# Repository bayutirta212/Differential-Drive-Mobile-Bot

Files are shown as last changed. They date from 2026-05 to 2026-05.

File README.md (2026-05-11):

# Differential Drive Bot PCB

Custom PCB design for a compact Differential Drive Robot using ESP32 DevKit V1 (30 Pin).

## Features

- Dual motor differential drive system
- Encoder feedback support
- OLED display integration
- Ultrasonic obstacle detection
- GPIO expansion using multiplexer
- Line tracking sensor support
- Compact PCB layout
- ESP32-based control system

---

# Hardware Components

- ESP32 DevKit V1 (30 Pin)
- JGA12 N20 Motor Encoder
- DRV8833 Dual Motor Driver
- HC-SR04 Ultrasonic Sensor
- SSD1306 OLED Display
- CD74HC4067 16-Channel Multiplexer
- TCRT5000 IR Reflective Sensor

---

# System Overview

This robot uses a differential drive mechanism where each wheel is independently controlled using the DRV8833 motor driver.

The ESP32 handles:
- Motor control
- Encoder reading
- OLED communication
- Ultrasonic sensing
- Multiplexer control
- Sensor data processing

The CD74HC4067 multiplexer is used to expand input capability while minimizing GPIO usage.

---

# Pin Configuration

## DRV8833 Motor Driver

| ESP32 Pin | Function |
|---|---|
| GPIO16 | Motor A IN1 |
| GPIO17 | Motor A IN2 |
| GPIO05 | Motor B IN1 |
| GPIO23 | Motor B IN2 |

---

## Motor Encoder

| ESP32 Pin | Function |
|---|---|
| GPIO39 | Left Encoder A |
| GPIO36 | Left Encoder B |
| GPIO35 | Right Encoder A |
| GPIO34 | Right Encoder B |

---

## HC-SR04

| ESP32 Pin | Function |
|---|---|
| GPIO19 | Trigger |
| GPIO18 | Echo |

---

## SSD1306 OLED (I2C)

| ESP32 Pin | Function |
|---|---|
| GPIO21 | SDA |
| GPIO22 | SCL |

---

## CD74HC4067 Multiplexer

| ESP32 Pin | Function |
|---|---|
| GPIO27 | S0 |
| GPIO26 | S1 |
| GPIO25 | S2 |
| GPIO33 | S3 |
| GPIO32 | SIG |
| GIPO13 | EN |

---

# Repository Contents

- Schematic files
- PCB layout files
- Gerber files
- 3D PCB preview
- Wiring references

---

# Software Compatibility

This project can be programmed using:
- Arduino IDE
- PlatformIO

Recommended Libraries:
- Adafruit SSD1306
- Adafruit GFX
- ESP32Encoder
- NewPing

---

# Applications

- Line follower robot
- Obstacle avoidance robot
- Autonomous mobile robot
- Educational robotics platform

---

# Future Improvements

- IMU integration
- Battery monitoring
- PID motor control
- WiFi telemetry
- ROS compatibility

---

# License

This project is open-source under the MIT License.

---

# Author

Rafael Subally  
Student at Mechatronics Engineering Education  
Universitas Negeri Yogyakarta

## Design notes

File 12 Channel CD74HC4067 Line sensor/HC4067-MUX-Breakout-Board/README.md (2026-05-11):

# HC4067-MUX-Breakout-Board
74HC4067 16-ch analog/digital MUX Breakout Board

This is the Eagle CAD representation of the 74HC4067 breakout board, which can be bought from Sparkfun, ICStation or even eBay and Aliexpress.

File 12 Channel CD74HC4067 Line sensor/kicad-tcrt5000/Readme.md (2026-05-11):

# Kicad Footprint and Symbol for tcrt5000 

## Credits

[3D Model](https://grabcad.com/library/tcrt5000-1) by [Aleksandr Motsjonov](https://grabcad.com/aleksandr.motsjonov-1)

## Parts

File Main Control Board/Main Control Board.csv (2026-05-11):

Reference | Qty | Value | DNP | Exclude from BOM | Exclude from Board | Footprint | Datasheet
Brd1 | 1 | SSD1306 |  |  |  | SSD1306:128x64OLED
C1 | 1 | 0.33uF |  |  |  | Capacitor_SMD:C_0805_2012Metric_Pad1.18x1.45mm_HandSolder
C2 | 1 | 0.1uF |  |  |  | Capacitor_SMD:C_0805_2012Metric_Pad1.18x1.45mm_HandSolder
J1 | 1 | Screw_Terminal_01x02 |  |  |  | TerminalBlock:TerminalBlock_MaiXu_MX126-5.0-02P_1x02_P5.00mm
J2 | 1 | Motor A |  |  |  | Connector_JST:JST_XH_B6B-XH-A_1x06_P2.50mm_Vertical
J3 | 1 | Motor B |  |  |  | Connector_JST:JST_XH_B6B-XH-A_1x06_P2.50mm_Vertical
J4 | 1 | Sensor LFR |  |  |  | Connector_PinHeader_2.54mm:PinHeader_1x08_P2.54mm_Vertical
R1,R2,R3,R4,R5,R6 | 6 | 1k |  |  |  | Resistor_SMD:R_1206_3216Metric_Pad1.30x1.75mm_HandSolder
R7,R8,R9,R10 | 4 | 10k |  |  |  | Resistor_SMD:R_1206_3216Metric_Pad1.30x1.75mm_HandSolder
SW1 | 1 | kanan |  |  |  | Button_Switch_THT:SW_PUSH_6mm
SW2 | 1 | kiri |  |  |  | Button_Switch_THT:SW_PUSH_6mm
SW3 | 1 | atas |  |  |  | Button_Switch_THT:SW_PUSH_6mm
SW4 | 1 | bawah |  |  |  | Button_Switch_THT:SW_PUSH_6mm
SW5 | 1 | select |  |  |  | Button_Switch_THT:SW_PUSH_6mm
SW6 | 1 | back |  |  |  | Button_Switch_THT:SW_PUSH_6mm
U1 | 1 |  |  |  |  | ESP32_Footprints:ESP32_30pin
U2 | 1 |  |  |  |  | DRV8833:DRV8833 Module
U3 | 1 | L7806 |  |  |  | Package_TO_SOT_THT:TO-220-3_Horizontal_TabUp | http://www.st.com/content/ccc/resource/technical/document/datasheet/41/4f/b3/b0/12/d4/47/88/CD00000444.pdf/files/CD00000444.pdf/jcr:content/translations/en.CD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
U4 | 1 | HC-SR04 |  |  |  | Connector_PinHeader_2.54mm:PinHeader_1x04_P2.54mm_Vertical

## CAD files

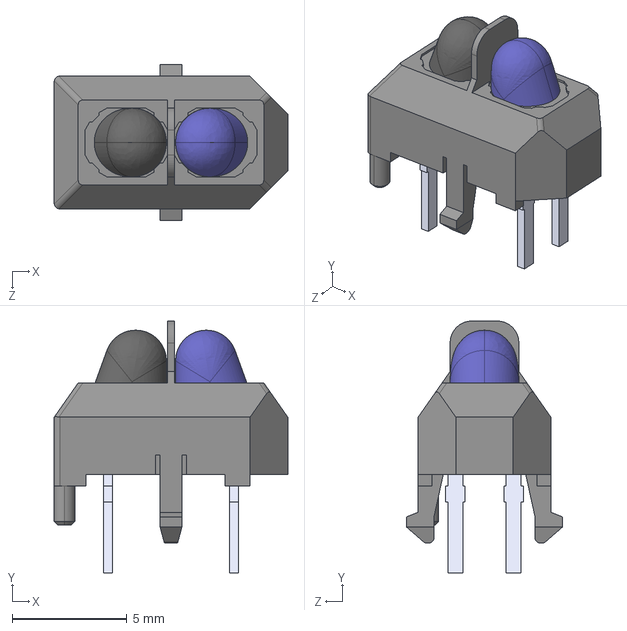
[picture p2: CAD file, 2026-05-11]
12 Channel CD74HC4067 Line sensor/kicad-tcrt5000/tcrt5000.step
10.2 x 11.0 x 6.80 mm

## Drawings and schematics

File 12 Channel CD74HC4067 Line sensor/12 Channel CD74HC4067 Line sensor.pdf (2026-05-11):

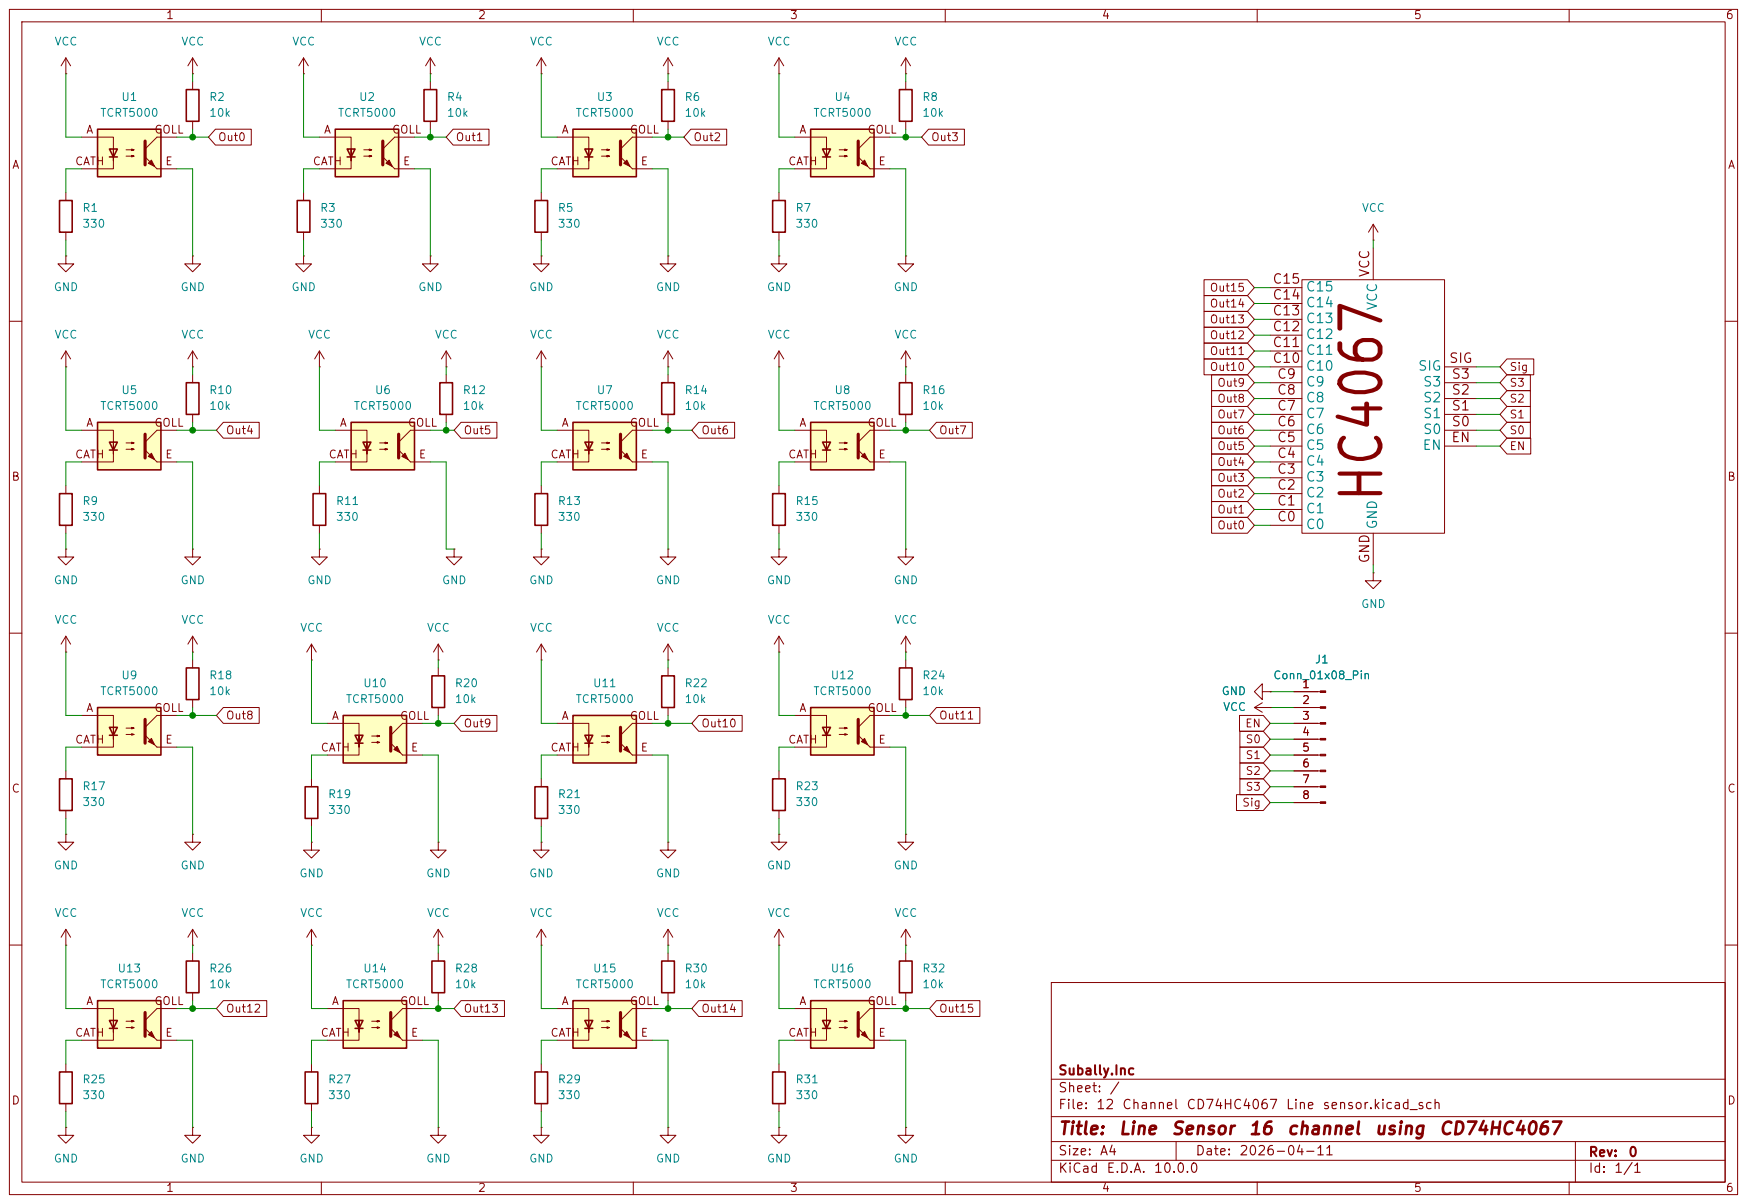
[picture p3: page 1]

Subally.Inc
Sheet: /
D Date: 2026-04-11 KiCad E.D.A. 10.0.0
File: 12 Channel CD74HC4067 Line sensor.kicad_sch
Title: Line Sensor 16 channel using CD74HC4067

Size: A4 | Rev: 0

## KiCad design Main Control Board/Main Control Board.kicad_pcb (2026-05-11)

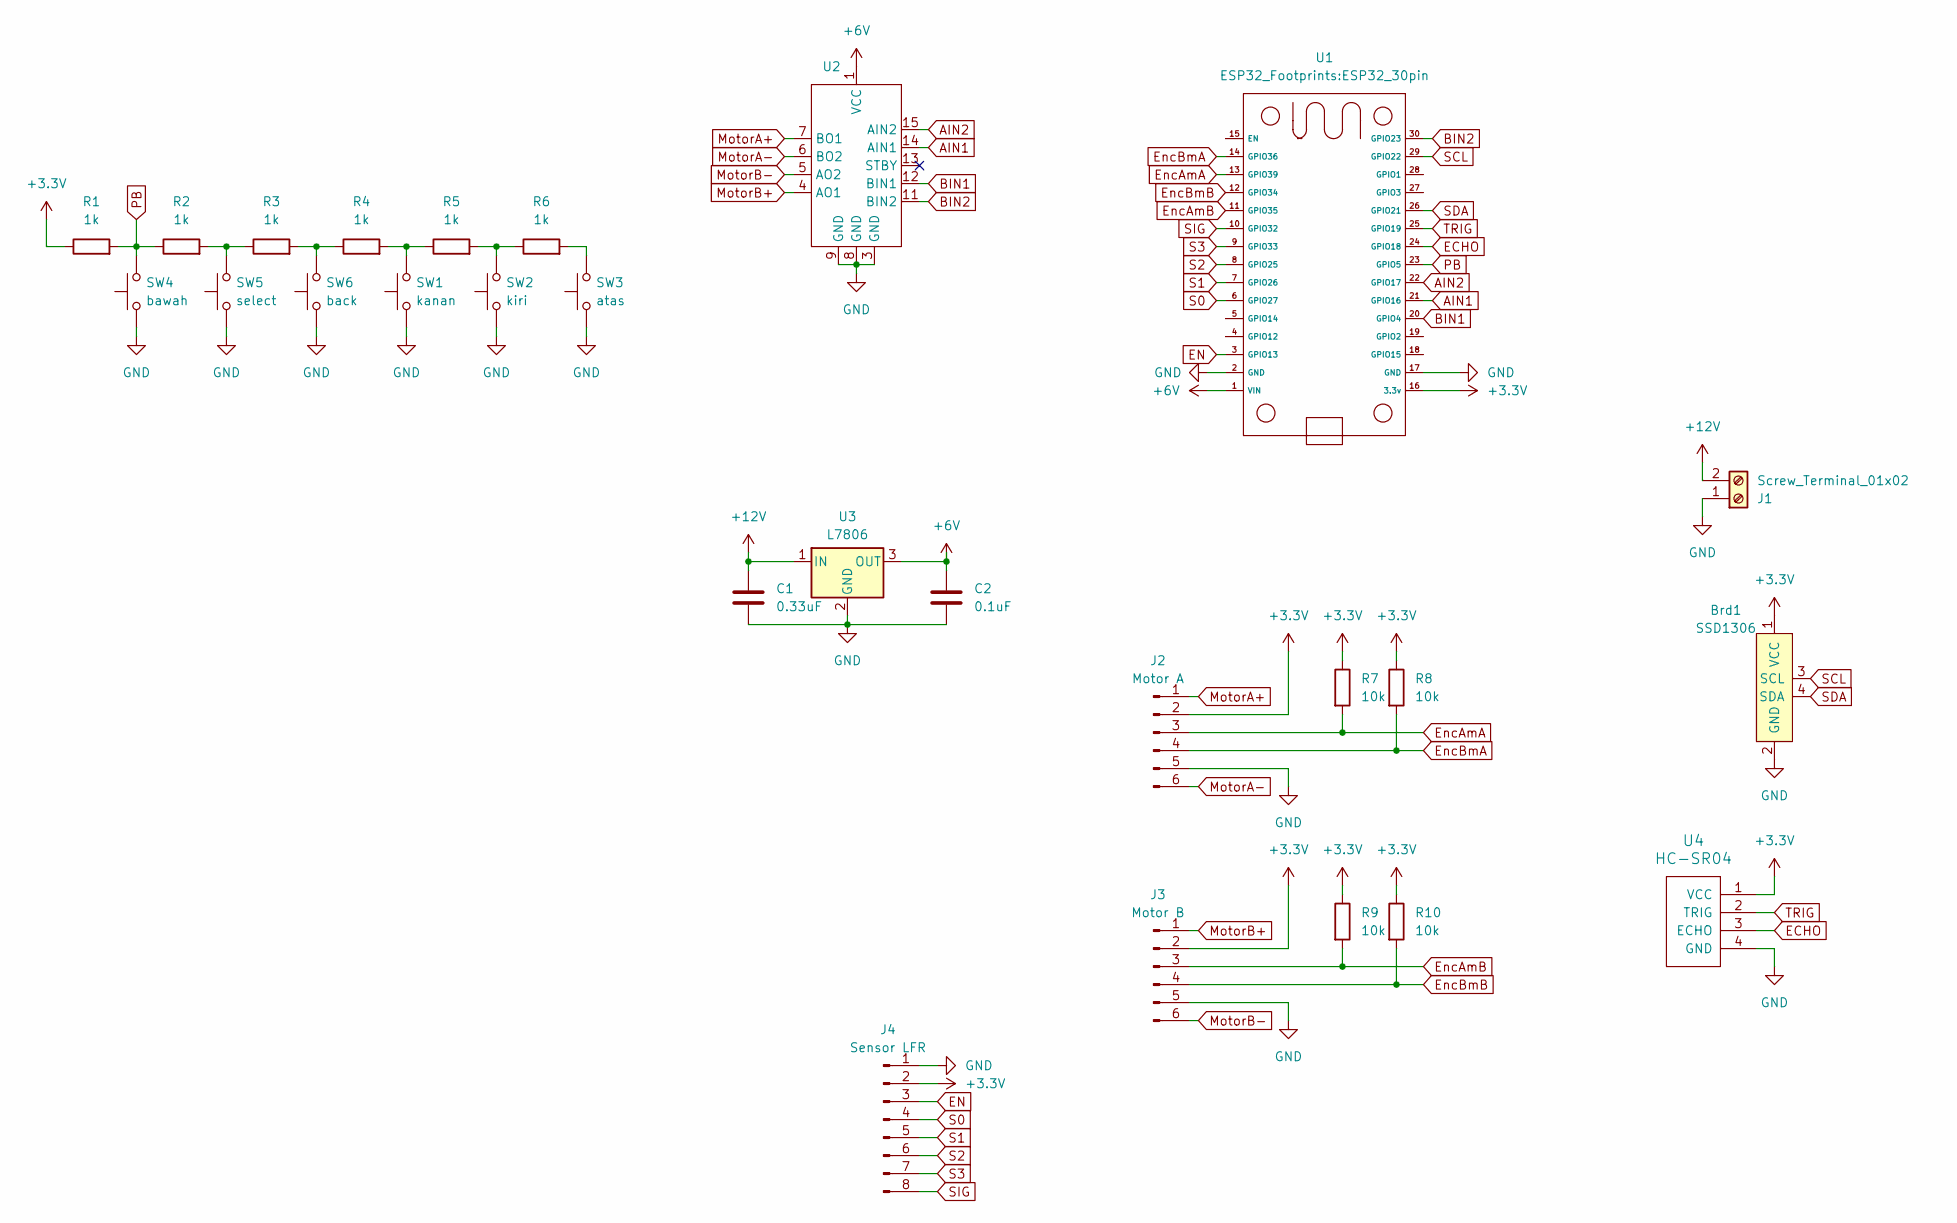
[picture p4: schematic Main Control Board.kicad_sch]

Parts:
Brd1: SSD1306; 128x64OLED
C1: 0.33uF; C_0805_2012Metric_Pad1.18x1.45mm_HandSolder
C2: 0.1uF; C_0805_2012Metric_Pad1.18x1.45mm_HandSolder
J1: Screw_Terminal_01x02; TerminalBlock_MaiXu_MX126-5.0-02P_1x02_P5.00mm
J2: Motor A; JST_XH_B6B-XH-A_1x06_P2.50mm_Vertical
J3: Motor B; JST_XH_B6B-XH-A_1x06_P2.50mm_Vertical
J4: Sensor LFR; PinHeader_1x08_P2.54mm_Vertical
R1, R2, R3, R4, R5, R6: 1k; R_1206_3216Metric_Pad1.30x1.75mm_HandSolder
R7, R8, R9, R10: 10k; R_1206_3216Metric_Pad1.30x1.75mm_HandSolder
SW1: kanan; SW_PUSH_6mm
SW2: kiri; SW_PUSH_6mm
SW3: atas; SW_PUSH_6mm
SW4: bawah; SW_PUSH_6mm
SW5: select; SW_PUSH_6mm
SW6: back; SW_PUSH_6mm
U1: ESP32_30pin
U2: DRV8833 Module
U3: L7806; TO-220-3_Horizontal_TabUp
U4: HC-SR04; PinHeader_1x04_P2.54mm_Vertical

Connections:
+3.3V: Brd1.1 (VCC), J2.2, J3.2, J4.2, R1.1, R7.1, R8.1, R9.1, R10.1, U1.16 (3.3v), U4.1 (VCC)
+6V: C2.1, U1.1 (VIN), U2.1 (VCC), U3.3 (OUT)
+12V: C1.1, J1.2, U3.1 (IN)
AIN1: U1.21 (GPIO16), U2.14 (AIN1)
AIN2: U1.22 (GPIO17), U2.15 (AIN2)
BIN1: U1.20 (GPIO4), U2.12 (BIN1)
BIN2: U1.30 (GPIO23), U2.11 (BIN2)
ECHO: U1.24 (GPIO18), U4.3 (ECHO)
EN: J4.3, U1.3 (GPIO13)
EncAmA: J2.3, R7.2, U1.13 (GPIO39)
EncAmB: J3.3, R9.2, U1.11 (GPIO35)
EncBmA: J2.4, R8.2, U1.14 (GPIO36)
EncBmB: J3.4, R10.2, U1.12 (GPIO34)
GND: Brd1.2 (GND), C1.2, C2.2, J1.1, J2.5, J3.5, J4.1, SW1.1, SW2.1, SW3.1, SW4.1, SW5.1, SW6.1, U1.2 (GND), U1.17 (GND), U2.3 (GND), U2.8 (GND), U2.9 (GND), U3.2 (GND), U4.4 (GND)
MotorA+: J2.1, U2.7 (BO1)
MotorA-: J2.6, U2.6 (BO2)
MotorB+: J3.1, U2.4 (AO1)
MotorB-: J3.6, U2.5 (AO2)
unnamed: R2.2, R3.1, SW5.2
unnamed: R3.2, R4.1, SW6.2
unnamed: R4.2, R5.1, SW1.2
unnamed: R5.2, R6.1, SW2.2
unnamed: R6.2, SW3.2
PB: R1.2, R2.1, SW4.2, U1.23 (GPIO5)
S0: J4.4, U1.6 (GPIO27)
S1: J4.5, U1.7 (GPIO26)
S2: J4.6, U1.8 (GPIO25)
S3: J4.7, U1.9 (GPIO33)
SCL: Brd1.3 (SCL), U1.29 (GPIO22)
SDA: Brd1.4 (SDA), U1.26 (GPIO21)
SIG: J4.8, U1.10 (GPIO32)
TRIG: U1.25 (GPIO19), U4.2 (TRIG)

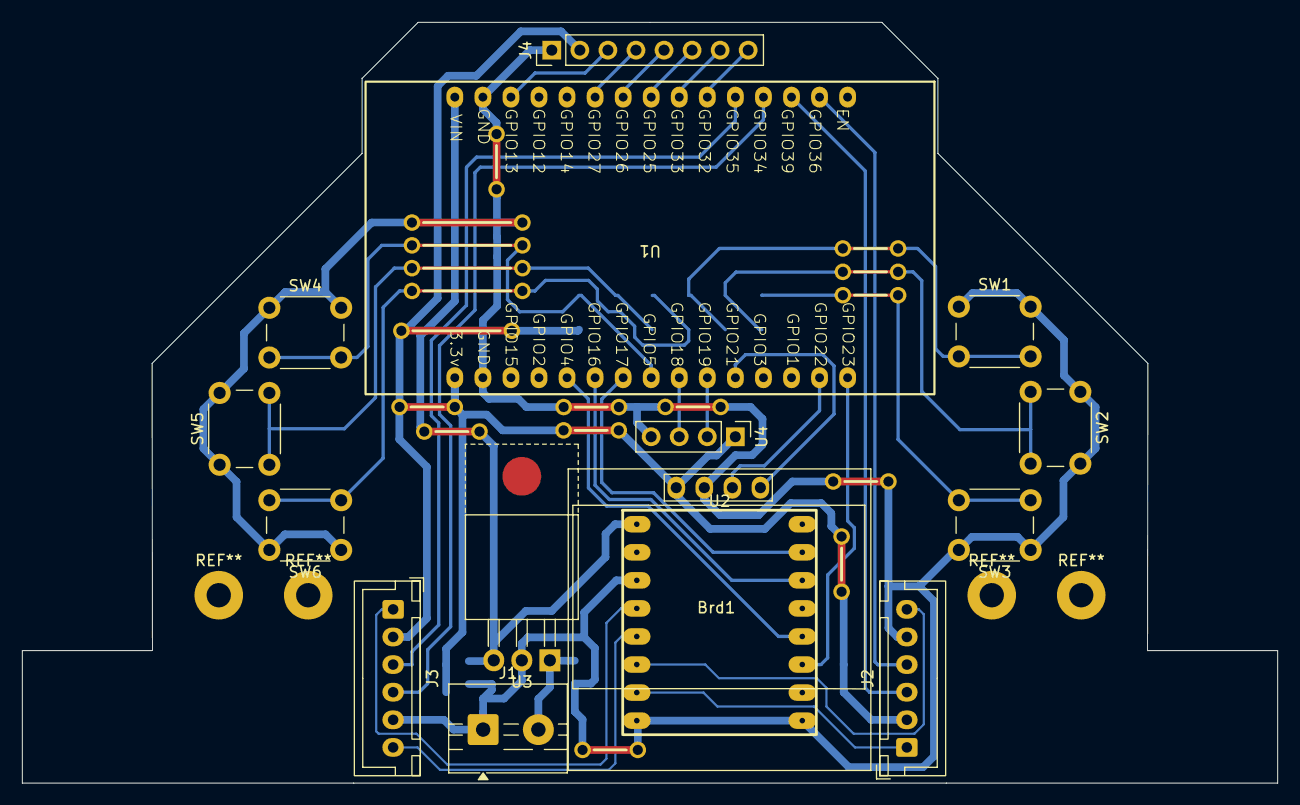
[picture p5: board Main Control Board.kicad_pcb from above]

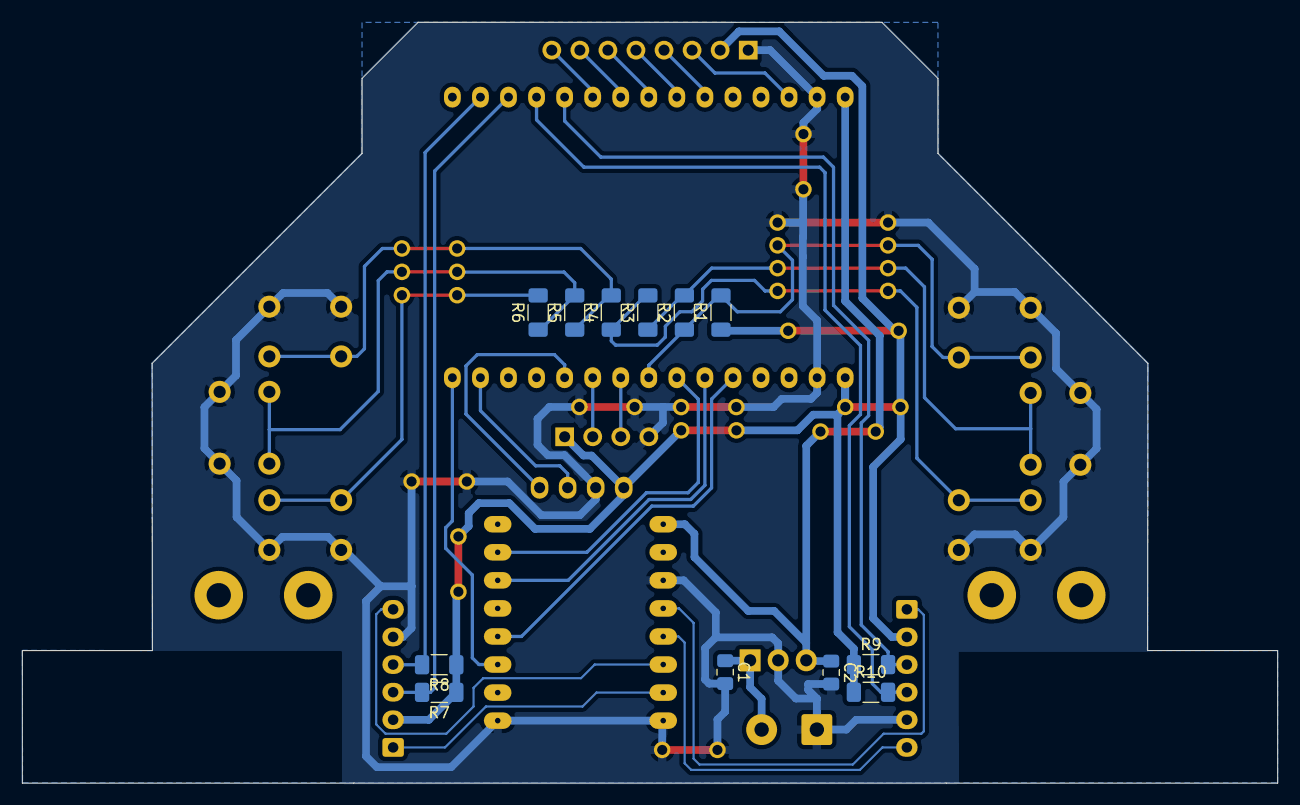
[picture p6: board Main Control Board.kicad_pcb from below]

Board: 4 copper layers, 113.6 x 68.9 mm, 27 parts (12 on the bottom side), 32 nets.

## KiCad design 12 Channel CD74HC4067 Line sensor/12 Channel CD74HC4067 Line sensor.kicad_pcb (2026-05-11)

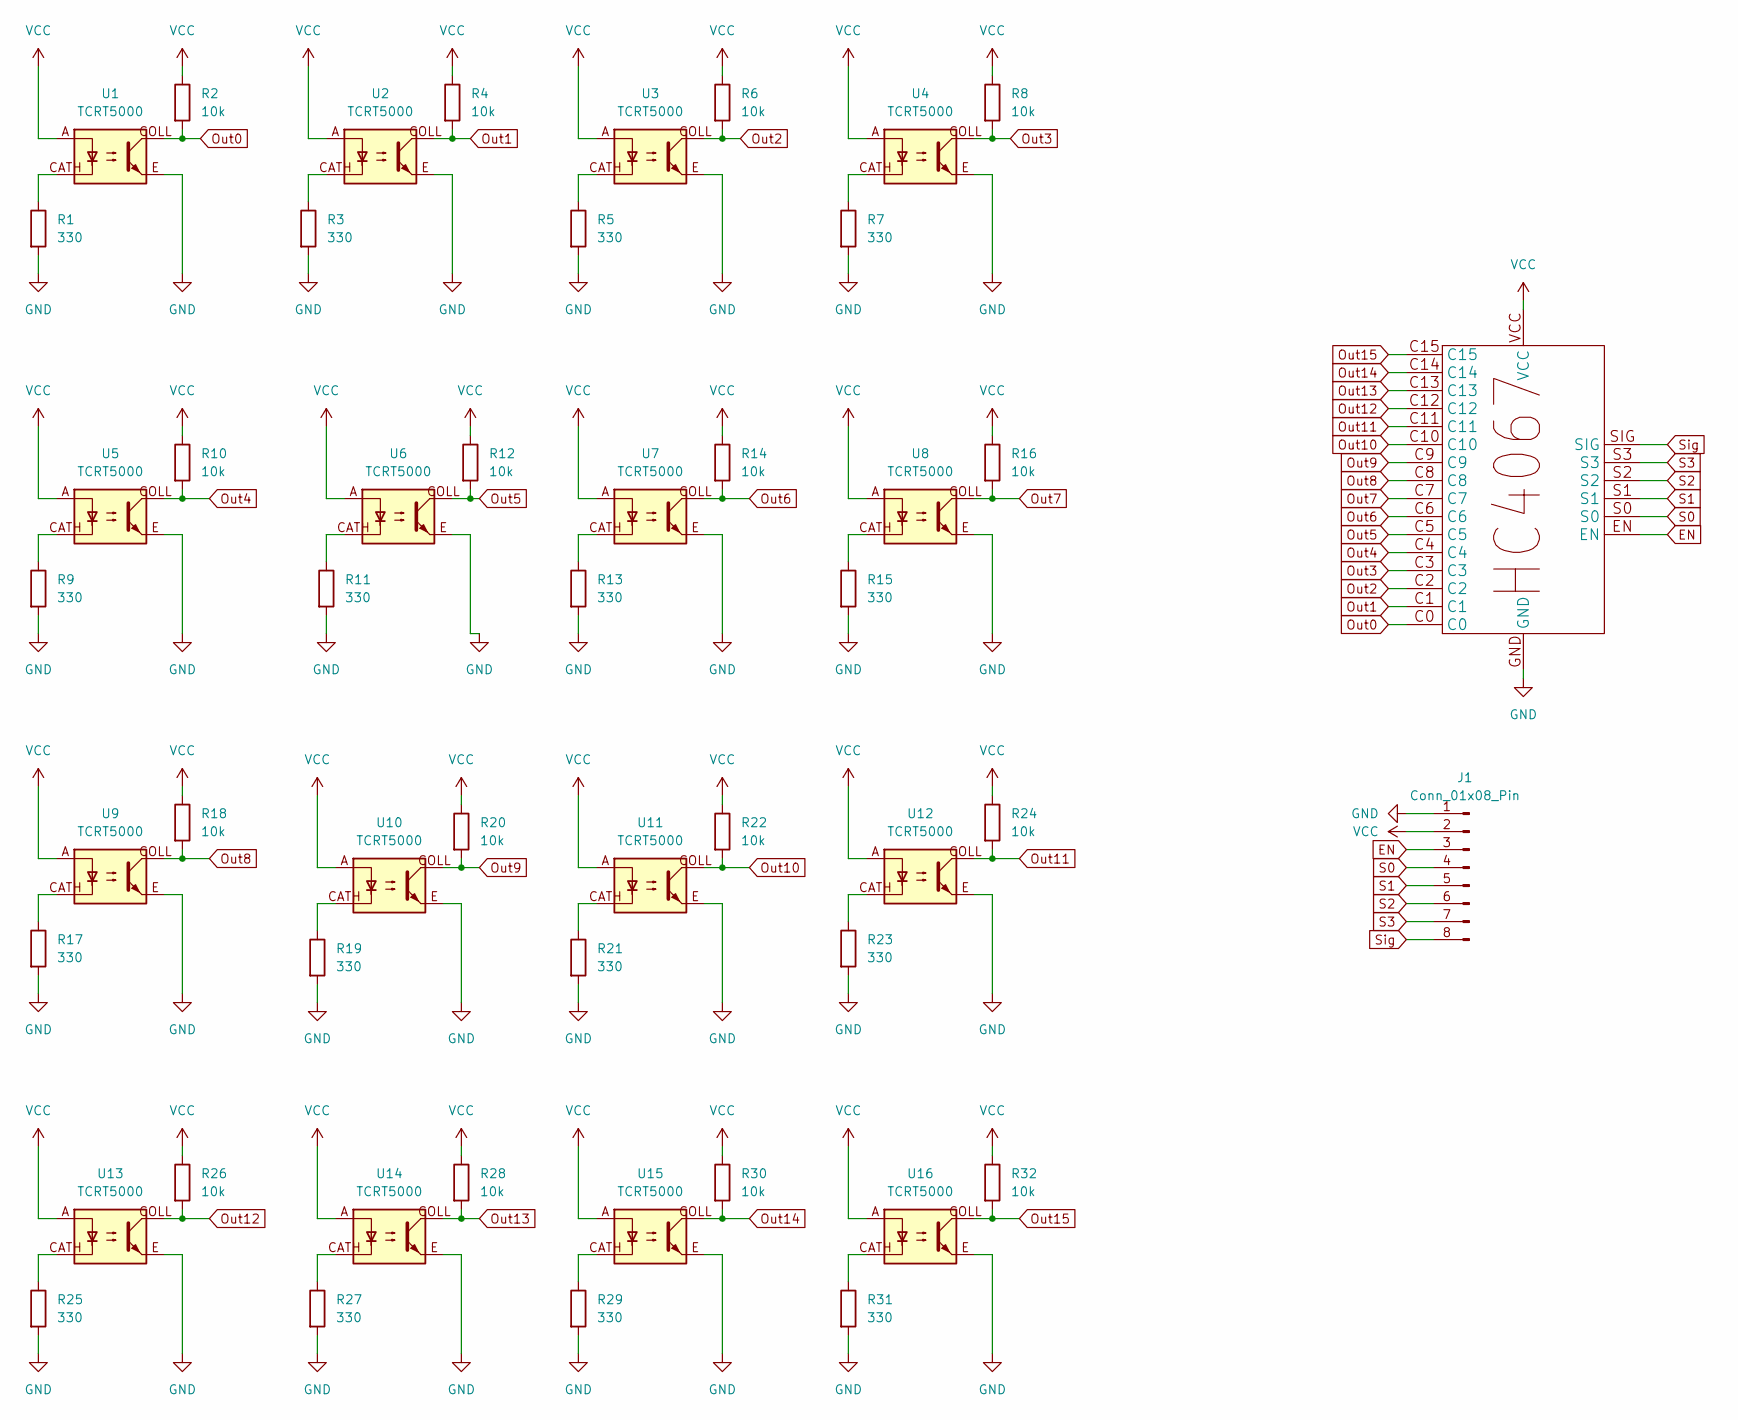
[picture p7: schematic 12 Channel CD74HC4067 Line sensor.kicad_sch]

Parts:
1: ANALOG_MUX_BREAKOUT_HC4067
J1: Conn_01x08_Pin; PinHeader_1x08_P2.54mm_Vertical
R1, R3, R5, R7, R9, R11, R13, R15, R17, R19, R21, R23, R25, R27, R29, R31: 330; R_1206_3216Metric_Pad1.30x1.75mm_HandSolder
R2, R4, R6, R8, R10, R12, R14, R16, R18, R20, R22, R24, R26, R28, R30, R32: 10k; R_1206_3216Metric_Pad1.30x1.75mm_HandSolder
U1, U2, U3, U4, U5, U6, U7, U8, U9, U10, U11, U12, U13, U14, U15, U16: TCRT5000; tcrt5000

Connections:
EN: 1.EN, J1.3
GND: 1.GND, J1.1, R1.2, R3.2, R5.2, R7.2, R9.2, R11.2, R13.2, R15.2, R17.2, R19.2, R21.2, R23.2, R25.2, R27.2, R29.2, R31.2, U1.E, U2.E, U3.E, U4.E, U5.E, U6.E, U7.E, U8.E, U9.E, U10.E, U11.E, U12.E, U13.E, U14.E, U15.E, U16.E
unnamed: R1.1, U1.CATH
unnamed: R3.1, U2.CATH
unnamed: R5.1, U3.CATH
unnamed: R7.1, U4.CATH
unnamed: R9.1, U5.CATH
unnamed: R11.1, U6.CATH
unnamed: R13.1, U7.CATH
unnamed: R15.1, U8.CATH
unnamed: R17.1, U9.CATH
unnamed: R19.1, U10.CATH
unnamed: R21.1, U11.CATH
unnamed: R23.1, U12.CATH
unnamed: R25.1, U13.CATH
unnamed: R27.1, U14.CATH
unnamed: R29.1, U15.CATH
unnamed: R31.1, U16.CATH
Out0: 1.C0, R2.2, U1.COLL
Out1: 1.C1, R4.2, U2.COLL
Out2: 1.C2, R6.2, U3.COLL
Out3: 1.C3, R8.2, U4.COLL
Out4: 1.C4, R10.2, U5.COLL
Out5: 1.C5, R12.2, U6.COLL
Out6: 1.C6, R14.2, U7.COLL
Out7: 1.C7, R16.2, U8.COLL
Out8: 1.C8, R18.2, U9.COLL
Out9: 1.C9, R20.2, U10.COLL
Out10: 1.C10, R22.2, U11.COLL
Out11: 1.C11, R24.2, U12.COLL
Out12: 1.C12, R26.2, U13.COLL
Out13: 1.C13, R28.2, U14.COLL
Out14: 1.C14, R30.2, U15.COLL
Out15: 1.C15, R32.2, U16.COLL
S0: 1.S0, J1.4
S1: 1.S1, J1.5
S2: 1.S2, J1.6
S3: 1.S3, J1.7
Sig: 1.SIG, J1.8
VCC: 1.VCC, J1.2, R2.1, R4.1, R6.1, R8.1, R10.1, R12.1, R14.1, R16.1, R18.1, R20.1, R22.1, R24.1, R26.1, R28.1, R30.1, R32.1, U1.A, U2.A, U3.A, U4.A, U5.A, U6.A, U7.A, U8.A, U9.A, U10.A, U11.A, U12.A, U13.A, U14.A, U15.A, U16.A

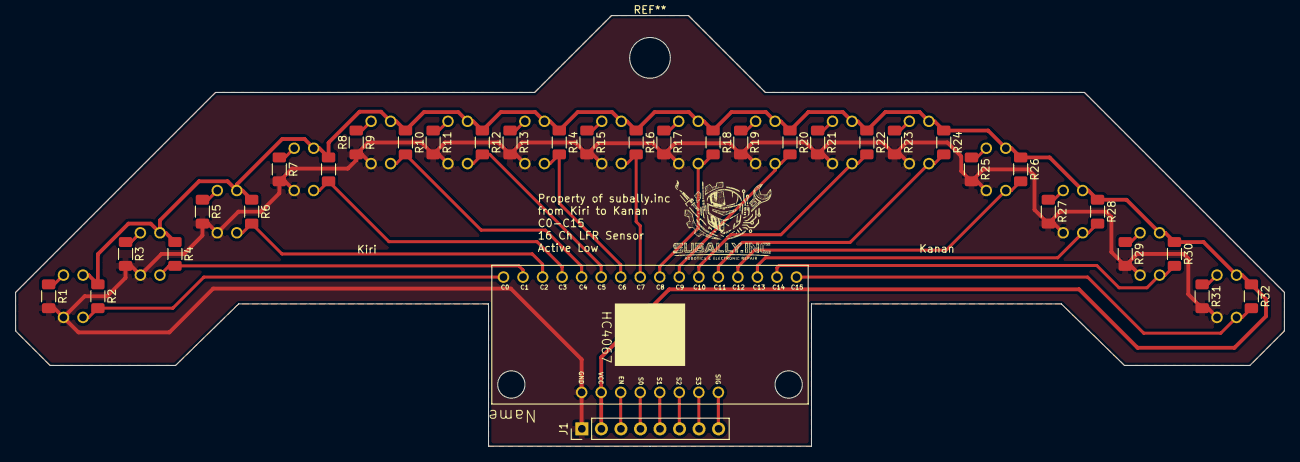
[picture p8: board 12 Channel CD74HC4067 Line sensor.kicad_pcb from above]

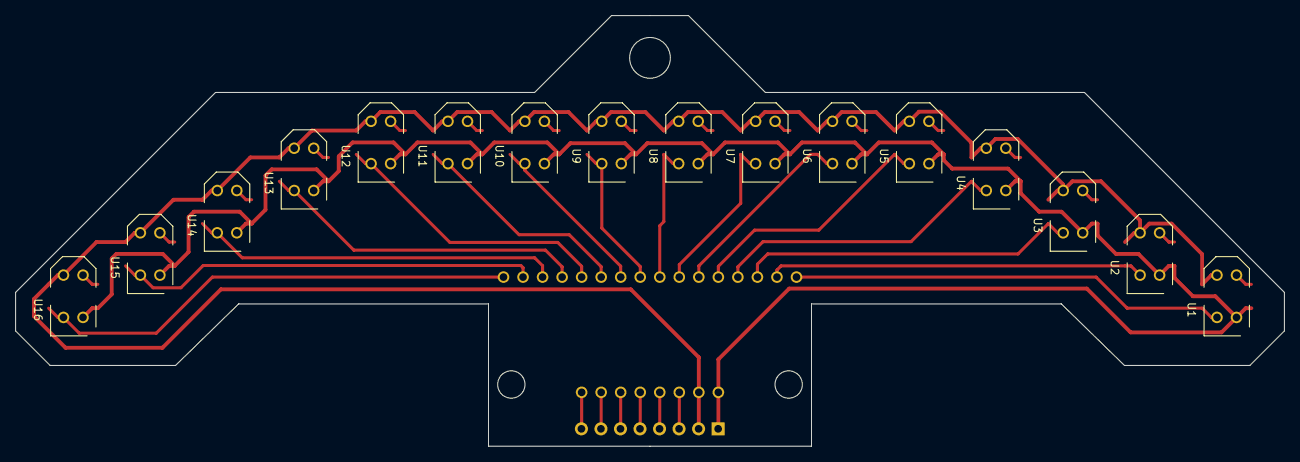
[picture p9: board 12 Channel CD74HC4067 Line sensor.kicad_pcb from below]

Board: 2 copper layers, 165.0 x 56.0 mm, 50 parts (16 on the bottom side), 40 nets.

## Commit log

2026-05-11 Update README with project details and documentation
    Added detailed documentation for the Differential Drive Bot PCB, including features, hardware components, system overview, pin configuration, repository contents, software compatibility, applications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
2026-05-11 Revise ESP32 pin assignments in README
    Updated ESP32 pin assignments for various components and removed the TCRT5000 section.
